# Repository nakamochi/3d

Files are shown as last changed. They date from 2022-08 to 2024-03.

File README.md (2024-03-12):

# nakamochi 3D designs

the repo contains 3D models of parts used in the nakamochi project.

those design sources which are made with [freecad](https://freecad.org/)
use a version no older than v0.20. a stock installation of freecad should
be sufficient but you might want to install
[fasteners workbench](https://wiki.freecadweb.org/Fasteners_Workbench) if working on
a design assembly.

there are currently designs only for the [NERD edition](https://nakamochi.io/#nerd).
KAFI version is coming later on. generated files like STL, STEP and DXF are attached
to their respective releases on https://git.qcode.ch/nakamochi/3d/releases

## NERD edition

this version features a custom heatsink combined with the bottom plate, suitable
for aluminium CNC milling. the construction provides a good heat dissipation,
making an active cooling like a fan redundant.

| | |
| ---|--- |
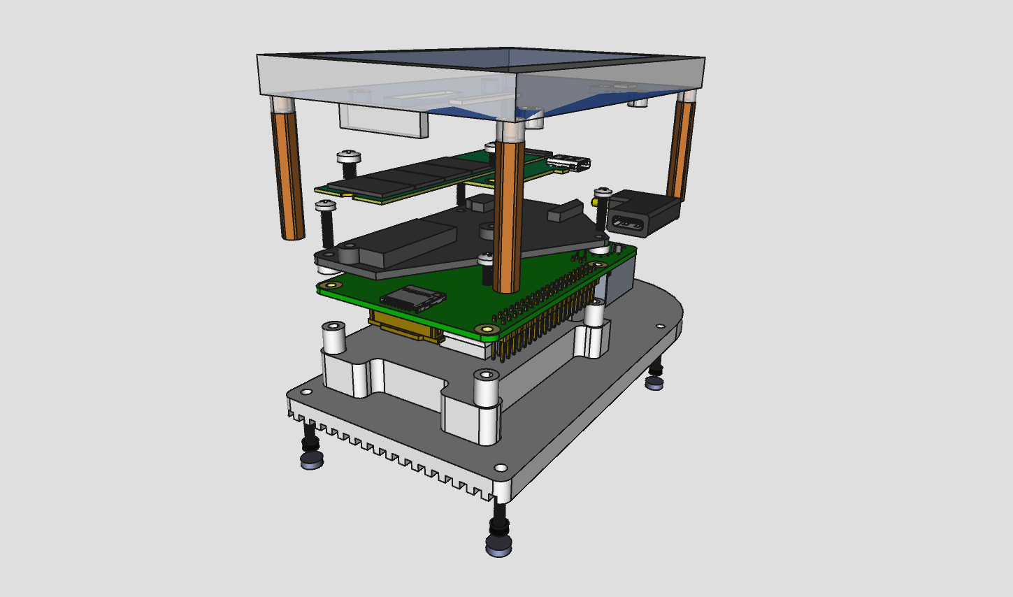
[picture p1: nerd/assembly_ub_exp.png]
NERD assembly unboxed exploded
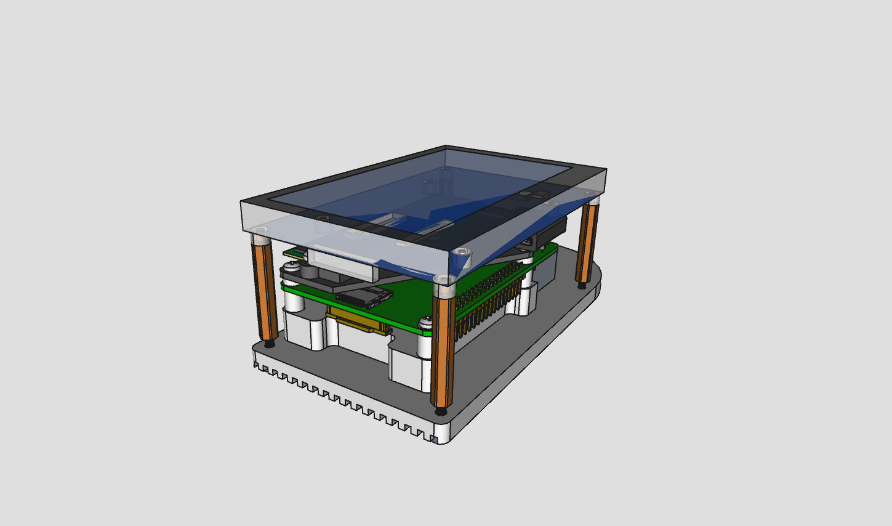
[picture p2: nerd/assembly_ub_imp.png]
NERD unboxed assembled
|  |  |
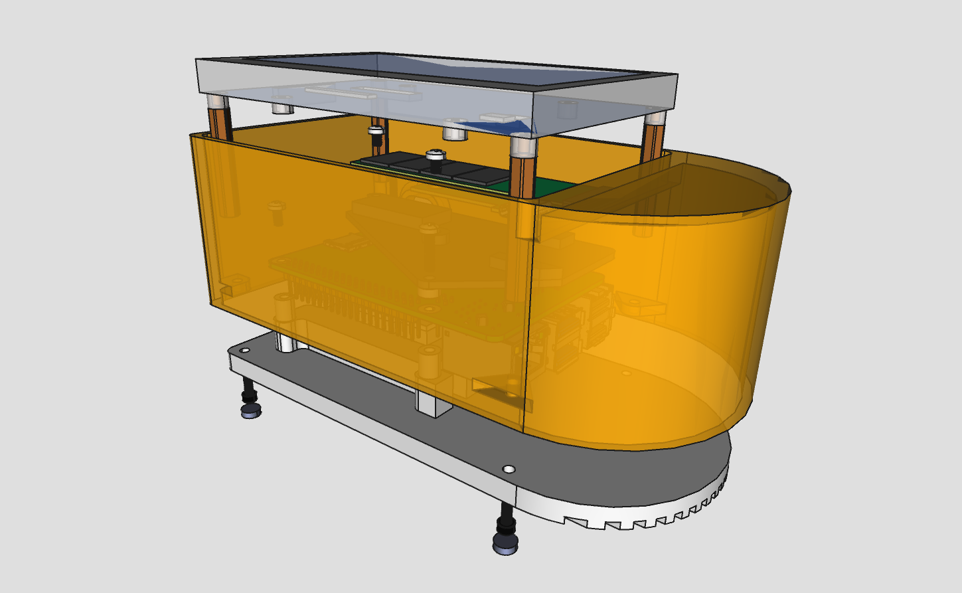
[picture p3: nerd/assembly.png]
NERD assembly
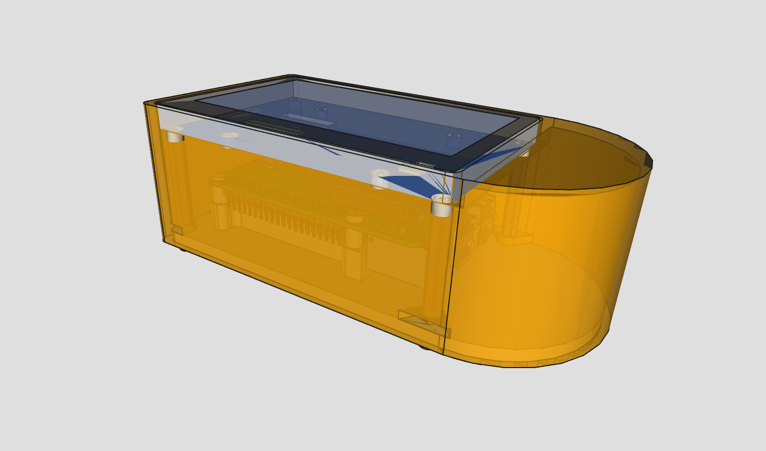
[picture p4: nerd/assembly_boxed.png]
NERD assembly boxed
|  |  |

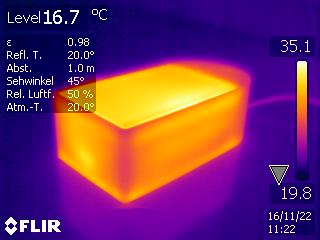
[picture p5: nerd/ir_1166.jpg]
NERD temperature during IBD

the baseplate serving as a heatsink brings down the main CPU temperature
from around 70℃  to 50℃. when measured externally while doing bitcoin initial
blocks download, an IR camera showed around 36℃.

the main file [nerd.FCStd](nerd/nerd.FCStd) contains all parts
as well as the assembly. a complete assembly BOM is as follows.

**off the shelf parts**

- [raspberry pi 4 model b][rpi4]
- [waveshare 4.3inch DSI LCD][lcd]
- [sandisk portable 1TB SSD sdssde30-1t00][ssd]
- 90 degree angle [USB-C adapter][usbc90deg] 3.1 gen 2, 10Gbps
- adhesive gasket/seal tape for LCD, 1mm thick, 10mm width, L370mm
- 3 thermal pads 1.5mm thick, 424mm sq total area - see baseplate drawing
- 7 screws M2.5 L10mm
- 4 adhesive bottom pads Ø5mm, 3mm+ thick

[rpi4]: https://www.raspberrypi.com/products/raspberry-pi-4-model-b/
[lcd]: https://www.waveshare.com/wiki/4.3inch_DSI_LCD
[ssd]: https://www.westerndigital.com/en-in/products/portable-drives/sandisk-usb-3-2-ssd
[usbc90deg]: https://www.delock.de/produkt/65915/merkmale.html

other parts, harvested from the above list:

- 2 self-tapping screws 2.9mm L3mm (from the SSD)
- 1 screw M2.5 L5mm (from the LCD)
- 4 PCB standoffs M2.5 L30mm (from the LCD)

**custom parts**

- CNC milled aluminium baseplate (look for `baseplate_techdraw_c.pdf` in releases)
- 3D-printed enclosure box (look for `box.stl` in releases)
- 3D-printed SSD support plate (look for `ssdsupport.stl` in releases)
- 3 Ø3mm hole 2.4mm thick spacers (use `spacer_3x2.4mm.stl` for 3D-print)

> TODO: assembly instructions

## assets

various files are placed in the [assets](assets/) to use in an assembly composition.
for example, you'll find a 4.3inch display, raspberry pi 4 and a heatsink in there.

when creating a design assembly, make a new [std part](https://wiki.freecad.org/Std_Part)
group and import desired assets into it. if an asset is in a freecad file format,
open the file and drag&drop the top level object into the newly created std part.
then close the original file ignoring the changes.

## license

[CC-BY 4.0](https://creativecommons.org/licenses/by/4.0/)

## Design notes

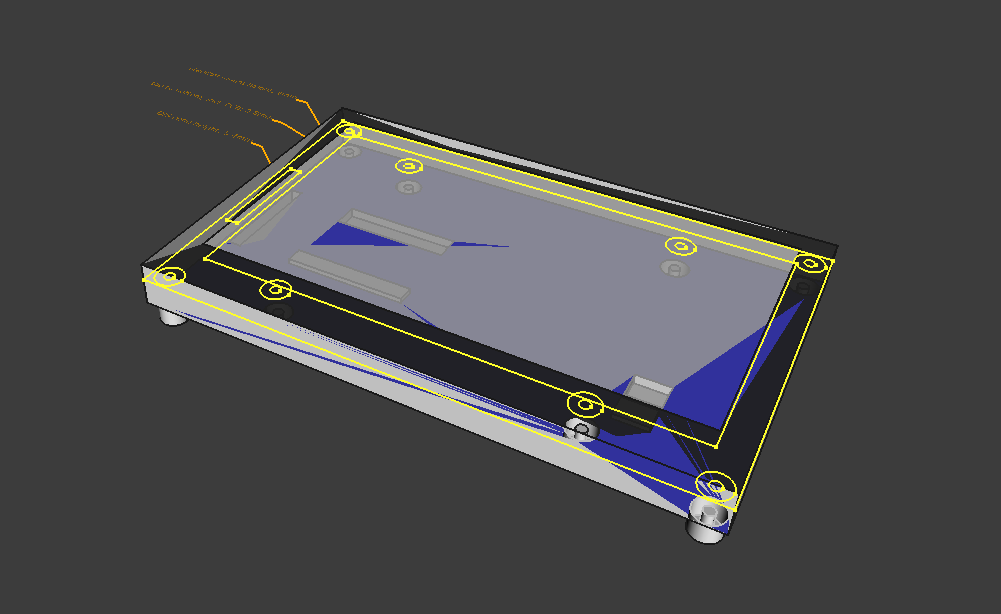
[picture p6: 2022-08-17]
assets/waveshare-4dot3inch-dsi-lcd.png

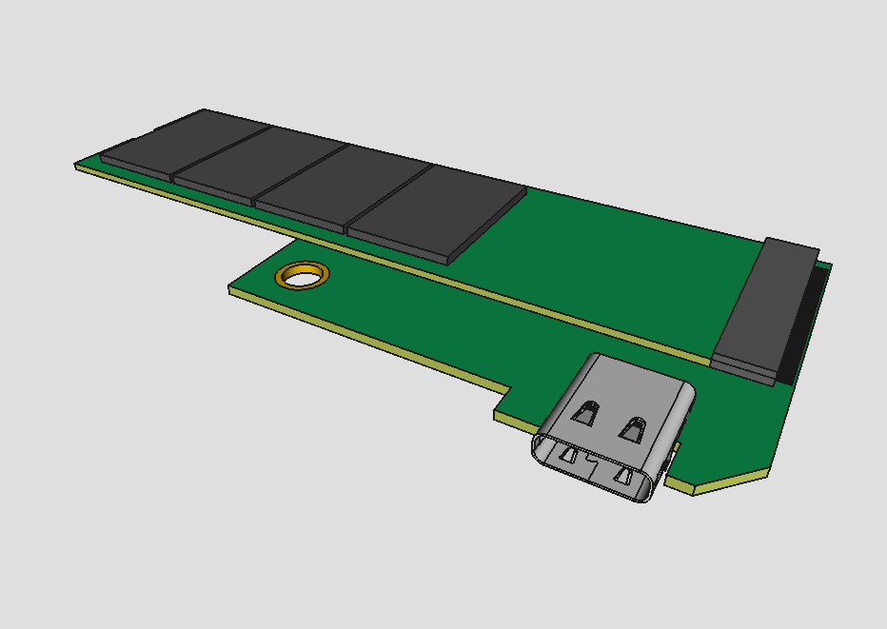
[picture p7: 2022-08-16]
assets/ssd-sdssde30-1t00-pcb.png

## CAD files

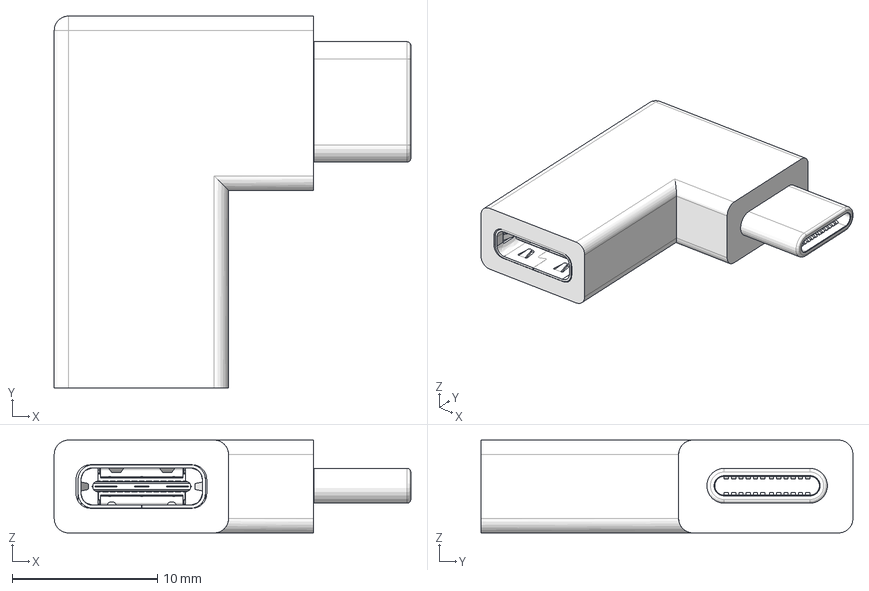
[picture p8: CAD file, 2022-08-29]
assets/usb-c-90deg-adapter.FCStd
24.5 x 25.6 x 6.40 mm

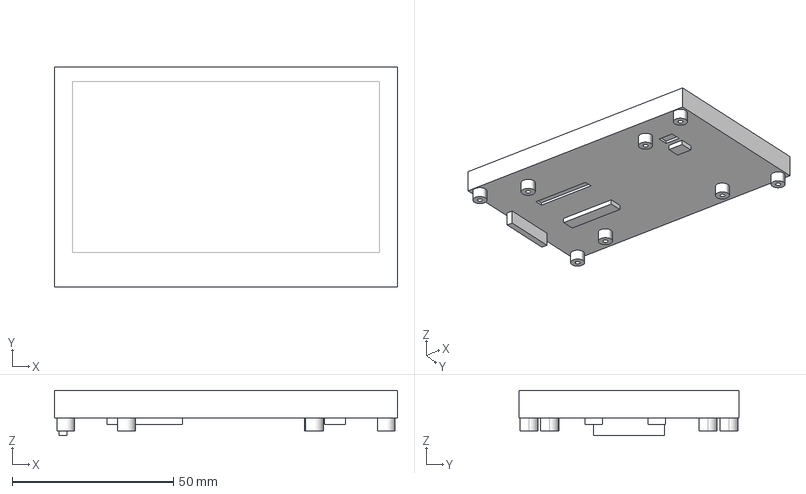
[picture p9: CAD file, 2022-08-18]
assets/waveshare-4dot3inch-dsi-lcd.FCStd
106.2 x 68.0 x 14.0 mm

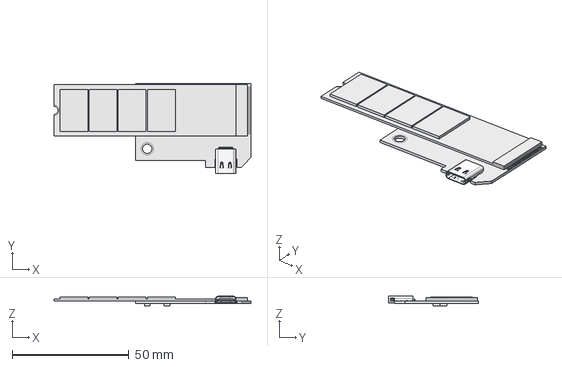
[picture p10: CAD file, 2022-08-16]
assets/ssd-sdssde30-1t00-pcb.FCStd
84.5 x 38.6 x 4.09 mm
pcb_body_refined
usb_c_refined

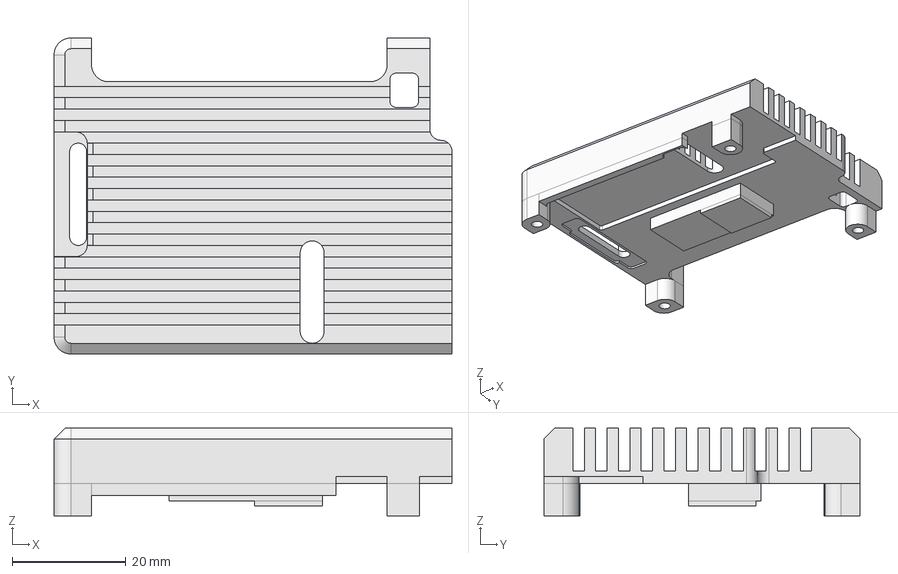
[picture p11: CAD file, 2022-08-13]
assets/joyit-armor-block-heatsink.FCStd
70.0 x 55.6 x 15.4 mm

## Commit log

2022-08-13 initial import
    certainly not ready for broad consumption yet.
    just sharing very early designs with friends.
    [joyit-armor-block-heatsink.FCStd, waveshare-4dot3inch-dsi-lcd.stp]
2022-08-14 fff: align all parts in the assembly
    all are parameterized via the asmsheet which now includes
    a calculation for an exploded view.
    while there, added the missing display standoffs.
    what's still missing is:
    - SSD board
    - heatsink top/bottom spacers
    - outer case walls and mount holes
2022-08-14 fff: add bottom sink screws to the assembly
    the standard hex with low head M3x10; comes with the display pkg.
2022-08-16 assets: add a simple model of sdssde30-1t00 pcb
    very simple, contains only the essential bits dimensions of which play
    important role in the case design due to size restrictions.
    there are two std parts: regular with sketches with sketches to
    construct the body, and a simple refined version for the provcase
    assembly.
    the regular variant also has a master sketch to aid in defining
    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
    [ssd-sdssde30-1t00-pcb.FCStd]
2022-08-16 fff: add the sdssde30-1t00 pcb to the assembly
    it shows in fact that the ssd pcb mounting pins in the provcase bottom
    part are slightly misplaced. will adjust in future commits.
2022-08-17 assets: add a master sketch to waveshare 4.3inch LCD
    this also means the STEP file is replaced with a freecad native file
    format.
    the master sketch comes in very handy when designing mount and other
    constructions around the LCD.
    [waveshare-4dot3inch-dsi-lcd.FCStd, waveshare-4dot3inch-dsi-lcd.stp]
2022-08-17 fff: adjust base plate to match the SSD PCB mount pins
    the SSD PCB sits very nicely now. the heatsink model has a pad at the
    bottom but it is not the case with the actual sink in use.
    will remove it later.
    the change also makes the base plate shorter, right about the size of
    the display: will be splitting the box in two to allow printing within a max
    circle area of 140mm diameter.
2022-08-18 assets: correct waveshare 4.3inch LCD rpi board mount points
    turns out either the original design is inaccurate or the freecad STEP
    import didn't work well: the rpi mounting screw holes were off but some
    sub millimeter length: 58.2x49.05 vs 58x49 actual.
    see rpi drawings in
    https://datasheets.raspberrypi.com/rpi4/raspberry-pi-4-mechanical-drawing.pdf
    [waveshare-4dot3inch-dsi-lcd.FCStd]
2022-08-18 fff: improve and split the assembly into a separate file
    this makes it a lot easier to work on a part and look at it in the
    assembled view by simply switching tabs. the separate file links to
    the original provcase.FCStd. so, need both files to work on the assembly.
    it is now possibly to simply select "exploded" or "assembled" option
    from a "view" property of the top level assembly std part: no need to
    manually modify the asmsheet. the property config is in the same
    spreadsheet.
    display standoff length now correctly offsets the LCD, the board and top
    heatsink while leaving the rest in place. so, it is very easy to change
    the overall height.
    this change also applies 4.3inch LCD updates from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
2022-08-18 fff: add walls around LCD to provcase
    with a standard M2 30mm PCB standoff for LCD, the walls' Z seems
    to magically settle on a nice round number of 48mm.
    [provcase.FCStd]
2022-08-20 fff: correct rpi board and top heatsink Z in provcase assembly
    were off by ~3mm lower. this will actually make a good Z for top/bottom
    heatsink spacer of about 5-6mm.
    [provcase.FCStd]
2022-08-21 fff: combine walls and the bottom plate to form a box
    makes it easier to 3d-print in the end.
    the plate and walls are still separate parts - easier to work on
    separately. it is also possible to even 3d-print them separately, in
    which case add a 0.5mm to clearance and plate mount Z in the params
    sheet.
    [provcase.FCStd]
2022-08-22 fff: add a side compartment part to close the gap
    the part is called sidecup. this is where cables reside, and possibly
    a custom PCB or a battery pack in the future.
    [provcase.FCStd]
2022-08-22 fff: add power cord and sd card access slots at the rear face
    [provcase.FCStd]
2022-08-22 fff: let air flow from sidecup bottom through LCD wall left face
    [provcase.FCStd]
2022-08-27 fff: fuse plate + walls into a new body and chamfer everywhere
    some first 3d print trials reveal the box might not be sufficiently strong
    and easy to print. adding chamfers and fillets helps.
    adding chamfers and fillets on plate/wall edges is much easier when the
    thing is a single body.
    [provcase.FCStd]
2022-08-29 assets: add a simple 90degree usb-c adapter
    turned out the cable connector attached to SSD is typically too long to
    fit. this 90deg adapter helps.
    the SSD is going to be connected to the main board via this adapter
    in the next commit.
    [usb-c-90deg-adapter.FCStd]
2022-08-29 fff: replace fused parts with a single body
    the fuse function in freecad didn't seem to work well when trying to go
    back and update individual body parts. this commit is essentially a
    remake of the plate + wall parts fuse from 6309e76 as a single body.
    the reason to go back and modify individual parts was to move SSD for
    more estate, to fit a 90deg connector because a straight cable doesn't
    fit.
    while there, added missing screws and spacers to the assembly.
    this version should be good to start 3d printing.
    [provcase.FCStd]
2022-10-05 fff: small final tweaks; stl files
    successfully printed a couple cases using 1.75 PLA, 0.4mm head,
    and assembled into a working prototype. all seem to fit together ok.
    [box.stl, provcase.FCStd, sidecup.stl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]
2023-01-15 fff: assembly cosmetic updates; no changes to the enclosure
    just shuffling parts around
2023-01-25 diyplus: a new and improved version compared to FFF
    this version features a custom heatsink combined with the bottom plate, suitable
    for aluminium CNC milling. the construction provides a better heat dissipation
    compared to the DIY (FFF) version.
    see all details in the readme.
    [baseplate_c.dxf, baseplate_c.step, baseplate_c.stl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]
2023-01-25 fff: update readme with a more detailed BOM and a build photo
2024-03-12 remove generated files - leave only sources
    any time FCStd sources are changed, the generated STL, STEP, DXF and
    other derivatives are no longer current. it makes more sense to post and
    tag the latter in releases.
    [baseplate_c.dxf, baseplate_c.step, baseplate_c.stl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]
2024-03-12 diyplus/ssdsupport: reduce SSD mount screw holes from 3mm to 2mm
    the screws are actually about 2.5mm in diameter, reused from SSD
    teardown. they are wide threaded, for plastic.
    3mm hole diameter was to accomodate for FDM 3D printers inaccuracies but
    it has shown to be too large, especially when produced with SLA or SLS
    method.
2024-03-12 delete fff version and rename diyplus into "nerd"
    this is to align with the naming scheme we came up on the website at
    https://nakamochi.io/#editions
    essentially, we merged fff, aka DIY, and DIY+ which lived in diyplus
    directory, into one called NERD. this is because the simplest DIY didn't
    provide acceptable performance characteristics and they are both
    suitable for a home-made DIY project anyway. hence, the "nerd" edition
    aka "have fun playing around with it on your own".
    it also makes things simpler. the other version we'll be making is KAFI.
    there are no source files for it yet.
    [provcase.FCStd]
2024-03-14 nerd/box: add wallstrips reinforcement
    a couple of strips on the long sides of the box walls to keep them
    straight.
2024-03-14 nerd/box: add a box mfr tolerance parameter
    earlier, some dimensions were sized as dy + a hardcoded 0.5mm as a way
    to adjust for FDM inaccuracy.
    with this commit, the adjustment is now moved to a new parameter
    box_mfr_tolerance so that it's easier to prepare for different tech
    process: FDM, SLA, jet, etc.
    the parameter is now set to 0mm because we're moving towards more
    accurate processes, SLA and jet. but it is always possible to set this
    back to 0.5mm or another value and generate an STL mesh file.
    just watch out for freecad's topo naming problem.
